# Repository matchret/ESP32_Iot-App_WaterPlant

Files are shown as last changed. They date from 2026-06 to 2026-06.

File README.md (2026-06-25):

# WaterPlant – ESP32 IoT & .NET MAUI App
.NET MAUI application communicating with an ESP32 via AWS IoT Core (Device Shadow) to monitor soil moisture and control an automated irrigation system.

The application allows users to monitor soil humidity, configure watering settings, manually water plants, and synchronize all settings through AWS IoT Device Shadow.

---

# Features

- 🌱 Monitor humidity for 4 plants
- 💧 Automatic watering
- 🎯 Configurable minimum and target humidity
- ⏱ Configurable pump duration
- ✅ Enable/disable each plant individually
- 🚰 Manual watering
- 🌎 Master enable/disable switch
- 🪣 Water tank level indicator
- ☁ AWS IoT Device Shadow synchronization
- 🌙 Dark / Light theme

---

# Project Structure

```
ESP32_Iot&App_WaterPlant/
│
├── WaterPlant_App/
│   ├── App.xaml
│   ├── App.xaml.cs
│   ├── MainPage.xaml
│   ├── MainPage.xaml.cs
│   ├── MauiProgram.cs
│   └── Services/
│       └── AwsIotShadowService.cs
│
└── Iot_Software/
    ├── src/
    │   └── main.cpp
    └── include/
        └── Secrets.hpp
```

---

# Build

Build command for apk android build:

```bash
dotnet publish -f net10.0-android -c Release -p:AndroidPackageFormat=apk
```

---

# Required Configuration

Before building the project on your own, complete the following files.

## 1. AWSIotShadowService.cs

File:

```
ESP32_Iot&App_WaterPlant/WaterPlant_App/Services/AWSIotShadowService.cs
```

Configure:

- AWS Access Key
- AWS Secret Key
- AWS Region
- Thing Name

Example:

```csharp
private readonly string _thingName = "YOUR_THING_NAME";

new BasicAWSCredentials(
    "YOUR_ACCESS_KEY",
    "YOUR_SECRET_KEY"
);
```

---

## 2. Secrets.hpp

File:

```
ESP32_Iot&App_WaterPlant/Iot_Software/include/Secrets.hpp
```

Configure:

```cpp
ssid
password

aws_endpoint
aws_port

root_ca
device_cert
private_key

shadowUpdateTopic
shadowDeltaTopic
mqtt_topic
```

---

# AWS Setup

To use this project, create and configure an AWS IoT Thing.

Required steps:

- Create an AWS IoT Thing
- Generate certificates
- Attach an IoT Policy
- Download:
  - Device certificate
  - Private key
  - Amazon Root CA
- Configure the Thing Name in both:
  - `AWSIotShadowService.cs`
  - `Secrets.hpp`
- Configure the AWS IoT endpoint

The application communicates using AWS IoT Device Shadow.

---

# User Interface

## Plant Monitoring

The application allows monitoring and controlling four independent plants.

Features include:

- Current soil humidity
- Humidity progress bar
- Minimum and target humidity range slider
- Pump duration adjustment
- Manual watering
- Individual enable/disable
- Dark/Light mode

<p align="center">
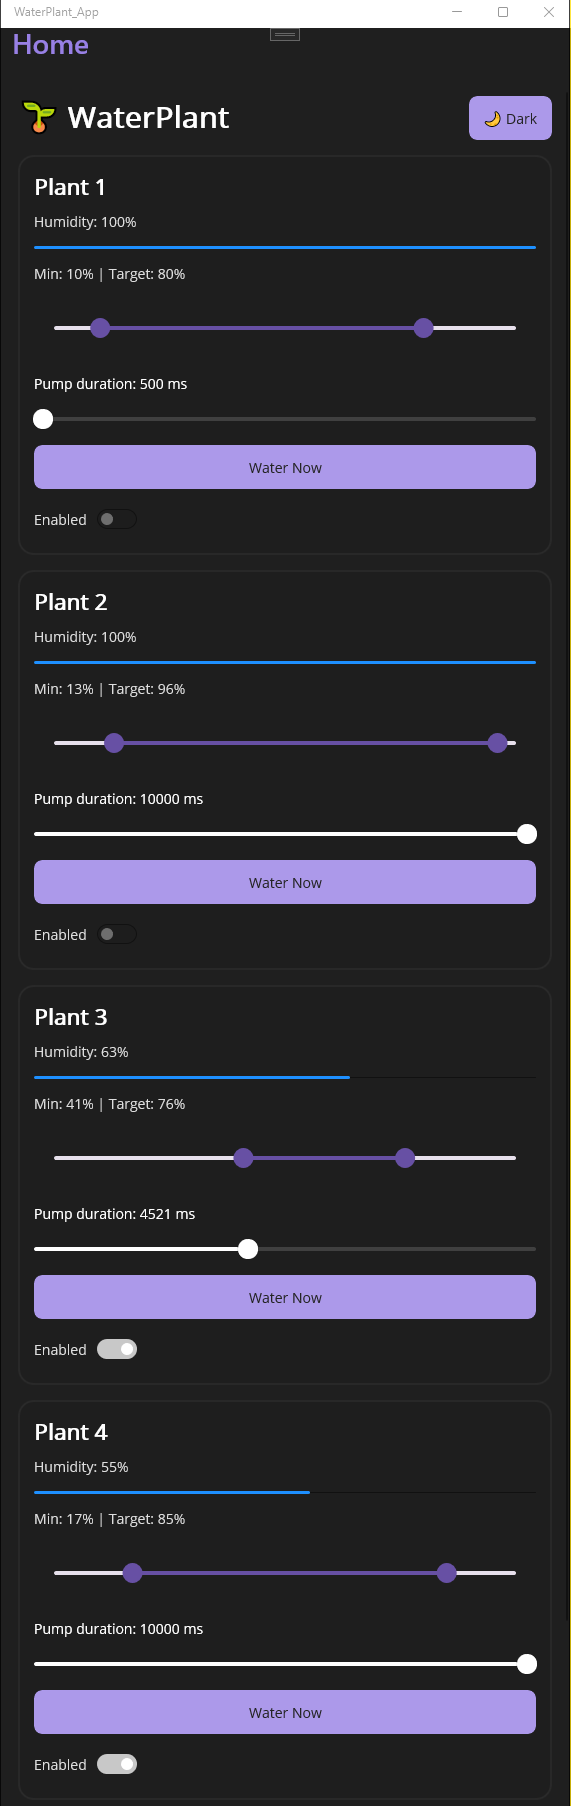
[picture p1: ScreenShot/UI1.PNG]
  
</p>

---

### Global Settings

The Global Settings section provides:

- Master control for all plants
- Water tank level indicator
- Apply/Discard pending changes
- Last synchronization time

<p align="center">
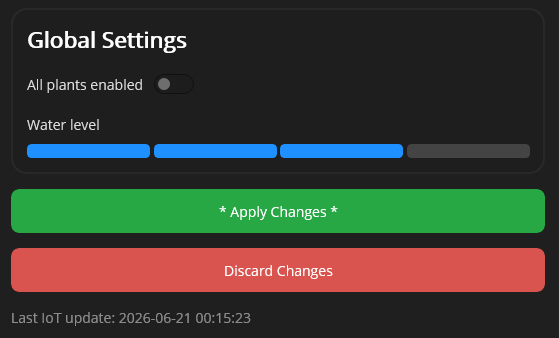
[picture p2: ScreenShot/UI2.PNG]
  
</p>

# ESP32 Logic

Every 15 minutes the ESP32:

1. Connects to AWS IoT
2. Reads water tank level
3. Reads soil humidity
4. Determines if watering is required
5. Waters until the target humidity is reached
6. Publishes the updated state to AWS IoT Shadow

Manual watering commands can also be received from AWS.

---

# Safety Features

- Pump duration limits
- Humidity limits
- Target humidity validation
- Plant enable/disable
- Maximum watering retries
- Low water protection

---

# Technologies

- ESP32
- Arduino
- C++
- .NET MAUI
- C#
- AWS IoT Core
- AWS Device Shadow
- MQTT
- WiFi

---

# License

This project was developed as a personal IoT learning project demonstrating embedded systems, cloud synchronization, and cross-platform application development.

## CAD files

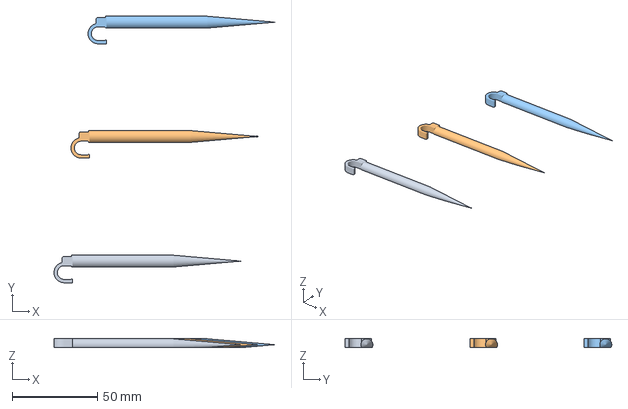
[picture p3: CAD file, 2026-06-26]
3DPrintedPart/HolderWaterTube.3mf
129.9 x 156.7 x 5.00 mm
holdersoil_clip_1 x 3

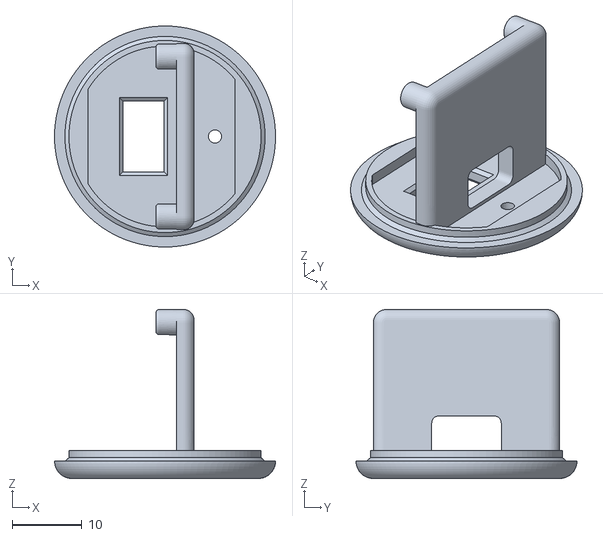
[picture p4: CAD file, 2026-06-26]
3DPrintedPart/CaseCover.stl
31.8 x 31.8 x 24.3

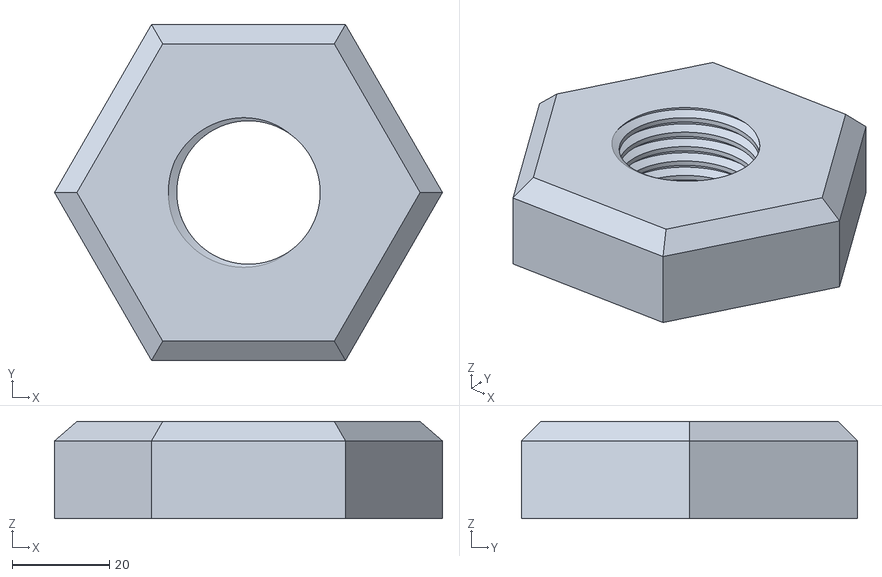
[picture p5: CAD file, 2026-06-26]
3DPrintedPart/LockNut_WaterSensor.stl
80.0 x 69.3 x 20.0

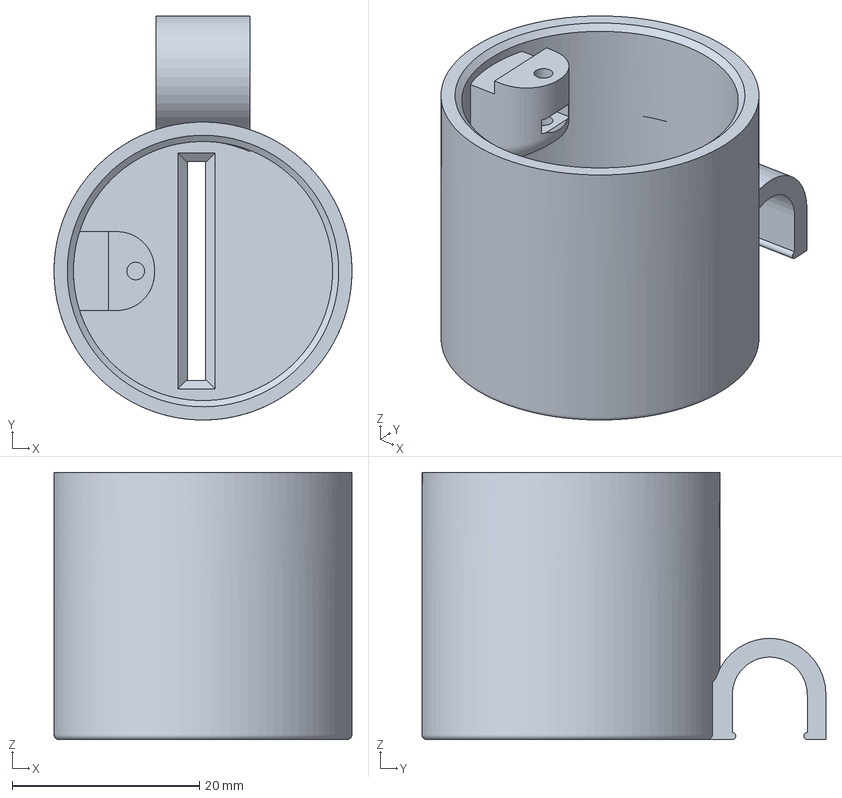
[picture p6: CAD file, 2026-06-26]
3DPrintedPart/CaseBody_ClipModif.3mf
31.8 x 43.1 x 28.5 mm

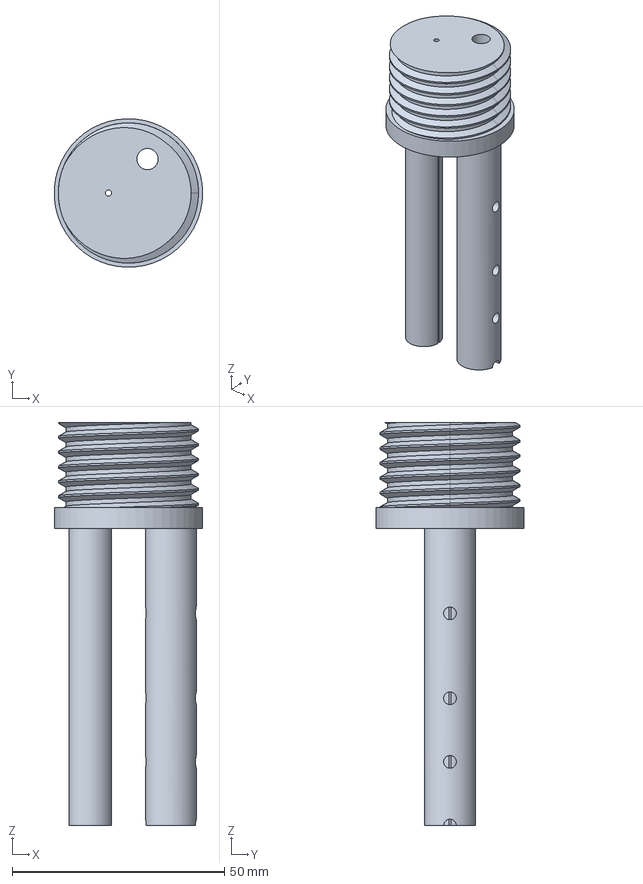
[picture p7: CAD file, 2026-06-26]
3DPrintedPart/WaterLevelSensor.FCStd
35.0 x 35.0 x 95.0 mm

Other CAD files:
3DPrintedPart/WaterLevelSensor.stl

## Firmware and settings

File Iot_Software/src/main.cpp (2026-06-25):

#include <Arduino.h>
#include <ArduinoJson.h>
#include <WiFi.h>
#include <WiFiClientSecure.h>
#include <PubSubClient.h>
#include "Secrets.h"

// ===== CLIENTS =====
WiFiClientSecure net;
PubSubClient client(net);

// Forward declaration
void messageHandler(char* topic, byte* payload, unsigned int length);


// ===== CONTROL =====
#define CONTROL1_PIN 16
#define CONTROL2_PIN 19
#define CONTROL3_PIN 21
#define CONTROL4_PIN 22


// ===== SENSOR HUMIDITY =====
#define SENSOR1_PIN 34
#define SENSOR2_PIN 35
#define SENSOR3_PIN 32
#define SENSOR4_PIN 33

// ===== WATER LEVEL =====
#define WATER_POWER_PIN 25

#define WATER_LEVEL_25_PIN 26
#define WATER_LEVEL_50_PIN 27
#define WATER_LEVEL_75_PIN 14
#define WATER_LEVEL_100_PIN 13

const int AirValue = 3450;
int WaterValue = 1700;

// ===== TIME SETTINGS =====
const int publishIntervalSeconds = 900; // 15 minutes
time_t lastPublishTime = 0;

// Settings par plante
int minHumidity[4] = {10, 10, 10, 10};        // % minimum
int targetHumidity[4] = {80, 80, 80, 80};     // % pour affichage
int pumpDuration[4] = {1000, 1000, 1000, 1000}; // ms d'activation
bool plantEnabled[4] = {false,false,false,false}; // si la plante est activée pour l'arrosage automatique


int sensorPins[4] = {SENSOR1_PIN, SENSOR2_PIN, SENSOR3_PIN, SENSOR4_PIN};
int controlPins[4] = {CONTROL1_PIN, CONTROL2_PIN, CONTROL3_PIN, CONTROL4_PIN};

void waterPlant(int plant) {
  digitalWrite(controlPins[plant], LOW);
  delay(pumpDuration[plant]);
  digitalWrite(controlPins[plant], HIGH);
}

// ===== WIFI CONNECT =====
void connectWiFi() {
  WiFi.begin(ssid, password);
  while (WiFi.status() != WL_CONNECTED) {
    delay(500);
    Serial.print(".");
  }
  Serial.println("\nWiFi connected");
}

void syncTime() {
  configTime(0, 0, "pool.ntp.org", "time.nist.gov");

  Serial.print("Waiting for NTP time");
  time_t now = time(nullptr);

  while (now < 1700000000) {
    delay(500);
    Serial.print(".");
    now = time(nullptr);
  }

  Serial.println("\nTime synced");
}

// ===== AWS CONNECT =====
void connectAWS() {
  net.setCACert(root_ca);
  net.setCertificate(device_cert);
  net.setPrivateKey(private_key);

  client.setServer(aws_endpoint, aws_port);
  client.setBufferSize(2048);
  client.setKeepAlive(60);
  client.setCallback(messageHandler);

  const char* clientId = "iot_frontier_waterPlant";

  Serial.print("Connecting to AWS IoT as ");
  Serial.println(clientId);

  if (client.connect(clientId)) {
    Serial.println("AWS IoT connected!");

    Serial.print("Subscribing to: ");
    Serial.println(shadowDeltaTopic);

    bool ok = client.subscribe(shadowDeltaTopic);

    if (ok) {
      Serial.println("Subscribed to shadow delta topic!");
    } else {
      Serial.println("FAILED to subscribe to shadow delta topic!");
    }
  } else {
    Serial.print("Failed, rc=");
    Serial.println(client.state());
  }
}

// ===== IoT =====

void messageHandler(char* topic, byte* payload, unsigned int length) {
  Serial.println("===== MESSAGE RECEIVED =====");
  Serial.print("Topic: ");
  Serial.println(topic);
  Serial.print("Payload: ");
  Serial.write(payload, length);
  Serial.println();

  JsonDocument doc;

  DeserializationError error = deserializeJson(doc, payload, length);

  if (error) {
    Serial.println("JSON parse failed");
    return;
  }

  JsonObject state = doc["state"];

 if (state["waterNow"].is<int>())
{
    int plant = state["waterNow"];

    Serial.printf("Manual watering plant %d\n", plant + 1);

    if (plant >= 0 && plant < 4 && plantEnabled[plant] && getWaterLevel() > 0)
    {
        waterPlant(plant);

        String report = "{";
        report += "\"state\":{";
        report += "\"reported\":{";
        report += "\"waterNow\":" + String(plant);
        report += "},";
        report += "\"desired\":{";
        report += "\"waterNow\":null";
        report += "}";
        report += "}}";

        client.publish(shadowUpdateTopic, report.c_str());
    }
}

  if (state["minHumidity"]) {
    for (int i = 0; i < 4; i++) {
      minHumidity[i] = constrain(state["minHumidity"][i].as<int>(), 0, 100);
    }
  }

  if (state["targetHumidity"]) {
  for (int i = 0; i < 4; i++) {
        targetHumidity[i] = constrain(state["targetHumidity"][i].as<int>(), 0, 100);

    if (targetHumidity[i] <= minHumidity[i]) {
      targetHumidity[i] = minHumidity[i] + 5;
    }
    targetHumidity[i] = constrain(targetHumidity[i], 0, 100);
  }
}

  if (state["pumpDuration"]) {
    for (int i = 0; i < 4; i++) {
      pumpDuration[i] = constrain(state["pumpDuration"][i].as<int>(), 500, 10000);
    }
  }

  if (state["plantEnabled"]) {
  for (int i = 0; i < 4; i++) {
    plantEnabled[i] = state["plantEnabled"][i].as<bool>();
  }
}

  Serial.println("Shadow settings updated");

  int humidity[4];
  for (int i = 0; i < 4; i++)
    humidity[i] = readHumidity(sensorPins[i]);

publishShadowState(humidity, getWaterLevel());
}

// ===== SETUP =====
void setupPins() {
  for (int i = 0; i < 4; i++) {
    pinMode(controlPins[i], OUTPUT);
    digitalWrite(controlPins[i], HIGH); // pompe OFF
  }

  pinMode(WATER_POWER_PIN, OUTPUT);
  digitalWrite(WATER_POWER_PIN, LOW);

  pinMode(WATER_LEVEL_25_PIN, INPUT_PULLDOWN);
  pinMode(WATER_LEVEL_50_PIN, INPUT_PULLDOWN);
  pinMode(WATER_LEVEL_75_PIN, INPUT_PULLDOWN);
  pinMode(WATER_LEVEL_100_PIN, INPUT_PULLDOWN);
}

void setup() {
  Serial.begin(115200);

  setupPins();

  connectWiFi();
  syncTime();
  connectAWS();
}

// ===== LOOP =====
int readHumidity(int pin) {
  int raw = analogRead(pin);
  int humidity = map(raw, AirValue, WaterValue, 0, 100);
  return constrain(humidity, 0, 100);
}


int getWaterLevel()
{
  digitalWrite(WATER_POWER_PIN, HIGH);
  delay(10);

  bool s25  = digitalRead(WATER_LEVEL_25_PIN);
  bool s50  = digitalRead(WATER_LEVEL_50_PIN);
  bool s75  = digitalRead(WATER_LEVEL_75_PIN);
  bool s100 = digitalRead(WATER_LEVEL_100_PIN);

  digitalWrite(WATER_POWER_PIN, LOW);

  if (s25 && s50 && s75 && s100) return 100;
  if (s25 && s50 && s75 && !s100) return 75;
  if (!s25 && s50 && s75 && !s100) return 50;
  if (!s25 && !s50 && s75 && !s100) return 25;
  if (!s25 && !s50 && !s75 && !s100) return 0;

  return -1; // sensor error / impossible pattern
}

void publishShadowState(int humidity[], int waterLevel)
{

    String payload = "{";
    payload += "\"state\":{\"reported\":{";

    payload += "\"humidity\":[";
    for (int i = 0; i < 4; i++) {
        payload += String(humidity[i]);
        if (i < 3) payload += ",";
    }
    payload += "],";

    payload += "\"minHumidity\":[";
    for (int i = 0; i < 4; i++) {
        payload += String(minHumidity[i]);
        if (i < 3) payload += ",";
    }
    payload += "],";

    payload += "\"targetHumidity\":[";
    for (int i = 0; i < 4; i++) {
        payload += String(targetHumidity[i]);
        if (i < 3) payload += ",";
    }
    payload += "],";

    payload += "\"pumpDuration\":[";
    for (int i = 0; i < 4; i++) {
        payload += String(pumpDuration[i]);
        if (i < 3) payload += ",";
    }
    payload += "],";

    payload += "\"plantEnabled\":[";
    for (int i = 0; i < 4; i++) {
        payload += plantEnabled[i] ? "true" : "false";
        if (i < 3) payload += ",";
    }
    payload += "],";

    payload += "\"waterLevel\":";
    payload += String(waterLevel);

    payload += "}}}";

    client.publish(shadowUpdateTopic, payload.c_str());
    client.publish(mqtt_topic, payload.c_str());

    Serial.println("Shadow updated.");
}


void loop() {
  if (!client.connected()) {
    connectAWS();
    delay(1000);
    return;
  }

  int waterLevel = getWaterLevel();

bool waterSafe = waterLevel > 0;

if (!waterSafe)
{
  Serial.println("Tank empty or water level sensor error - watering disabled");
}

  client.loop(); // must run often for AWS messages

  time_t now = time(nullptr);

  if (now - lastPublishTime < publishIntervalSeconds) {
    return;
  }

  lastPublishTime = now;

  int humidity[4];

  for (int i = 0; i < 4; i++) {
    humidity[i] = readHumidity(sensorPins[i]);

    if (waterSafe && plantEnabled[i] && humidity[i] < minHumidity[i])  {
      int tries = 0;

      while (humidity[i] < targetHumidity[i] && tries < 3) {
        waterPlant(i);

        unsigned long waitStart = millis();
        while (millis() - waitStart < 60000) {
          client.loop();
          delay(100);
        }

        humidity[i] = readHumidity(sensorPins[i]);
        tries++;
      }
    }
  }

  publishShadowState(humidity, waterLevel);
}

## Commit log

2026-06-25 Add water level sensor on Iot and app
2026-06-26 3d print file
    [CaseBody_ClipModif.3mf, CaseCover.stl, HolderWaterTube.3mf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]
